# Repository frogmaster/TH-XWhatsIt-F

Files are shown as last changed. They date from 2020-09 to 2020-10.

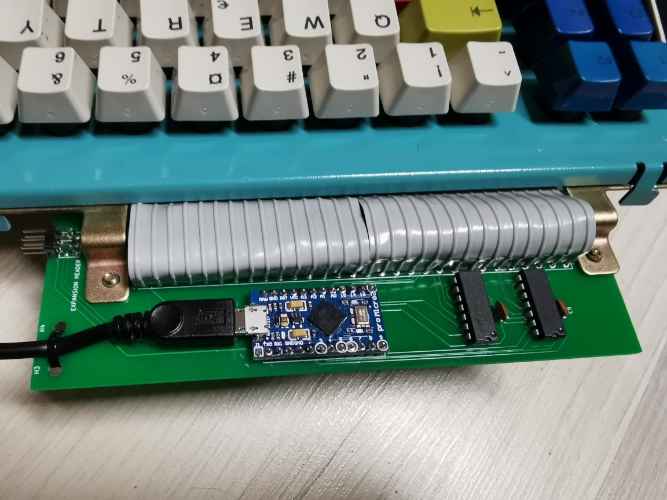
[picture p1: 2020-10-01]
model_f_at_board.jpg

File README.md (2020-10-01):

Derived from:

https://github.com/listofoptions/TH-XWhatsIt

through hole implementation of the capsense controllers by XWhatsIt
(Tom Wong-Cornell). original liscencure holds, as well as CERN OSH
(compatible license).

original implementation of Tom Wong-Cornell's controller documented here

http://downloads.cornall.co/ibm-capsense-usb-web/ibm-capsense-usb.html

component documentation is supplied, working theory of operation is under
the previous link.

Layout changed to accomodate IBM Model F PC/AT keyboard, mainly because i have that one. 
May fit other model F-s with similar setup.

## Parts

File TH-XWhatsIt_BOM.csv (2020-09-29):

Id | Designator | Package | Quantity | Designation | Supplier and ref
1 | U7 | ProMicro | 1 | ProMicro
2 | J2 | PinHeader_1x12_P2.54mm_Vertical | 1 | ROWS
3 | J1 | PinHeader_1x27_P2.54mm_Vertical | 1 | COLUMNS
4 | J8 | PinSocket_1x12_P2.54mm_Vertical | 1 | BEAMSPRING PLUGBOARD ROWS
5 | J11 | PinSocket_1x12_P2.54mm_Vertical | 1 | DISPLAYWRITER PLUGBOARD ROWS
6 | J5 | PinSocket_1x12_P2.54mm_Vertical | 1 | MODEL F PLUGBOARD ROWS
7 | J9 | PinSocket_1x27_P2.54mm_Vertical | 1 | DISPLAYWRITER PLUGBOARD COLUMNS
8 | J3 | PinSocket_1x27_P2.54mm_Vertical | 1 | MODEL F PLUGBOARD COLUMNS
9 | J6 | PinSocket_1x27_P2.54mm_Vertical | 1 | BEAMSPRING PLUGBOARD COLUMNS
10 | J10 | DIP-60_155_ELL | 1 | DISPLAYWRITER PLUGBOARD CONNECTOR
11 | J4 | PinHeader_1x30_P2.54mm_Horizontal | 1 | MODEL F PLUGBOARD CONNECTOR
12 | J7 | 3..6mm_cardedge | 1 | BEAMSPRING PLUGBOARD CONNECTOR
13 | U1,U6 | DIP-14_W7.62mm | 2 | LM339
14 | R6,R5,R1 | R_Axial_DIN0204_L3.6mm_D1.6mm_P1.90mm_Vertical | 3 | 4K7
15 | R2,R7 | R_Axial_DIN0204_L3.6mm_D1.6mm_P1.90mm_Vertical | 2 | 1K
16 | RN3,RN1 | R_Array_SIP5 | 2 | 100K
17 | J12 | PinHeader_2x03_P2.54mm_Vertical | 1 | EXPANSION HEADER
18 | RN2,RN4 | R_Array_SIP5 | 2 | 10K
19 | C3,C4,C5,C7,C8,C9,C10 | C_Disc_D3.0mm_W1.6mm_P2.50mm | 7 | 0U1
20 | R3,R4 | R_Axial_DIN0204_L3.6mm_D1.6mm_P1.90mm_Vertical | 2 | 20K
21 | U2 | DIP-8_W7.62mm | 1 | MCP4921-EP
22 | U8,U5,U3 | DIP-16_W7.62mm | 3 | 74HCT595
23 | C2 | C_Disc_D3.0mm_W1.6mm_P2.50mm | 1 | 10U
24 | H1,H2,H3,H4 | MountingHole_2.2mm_M2_Pad_Via | 4 | GROUND STRAP

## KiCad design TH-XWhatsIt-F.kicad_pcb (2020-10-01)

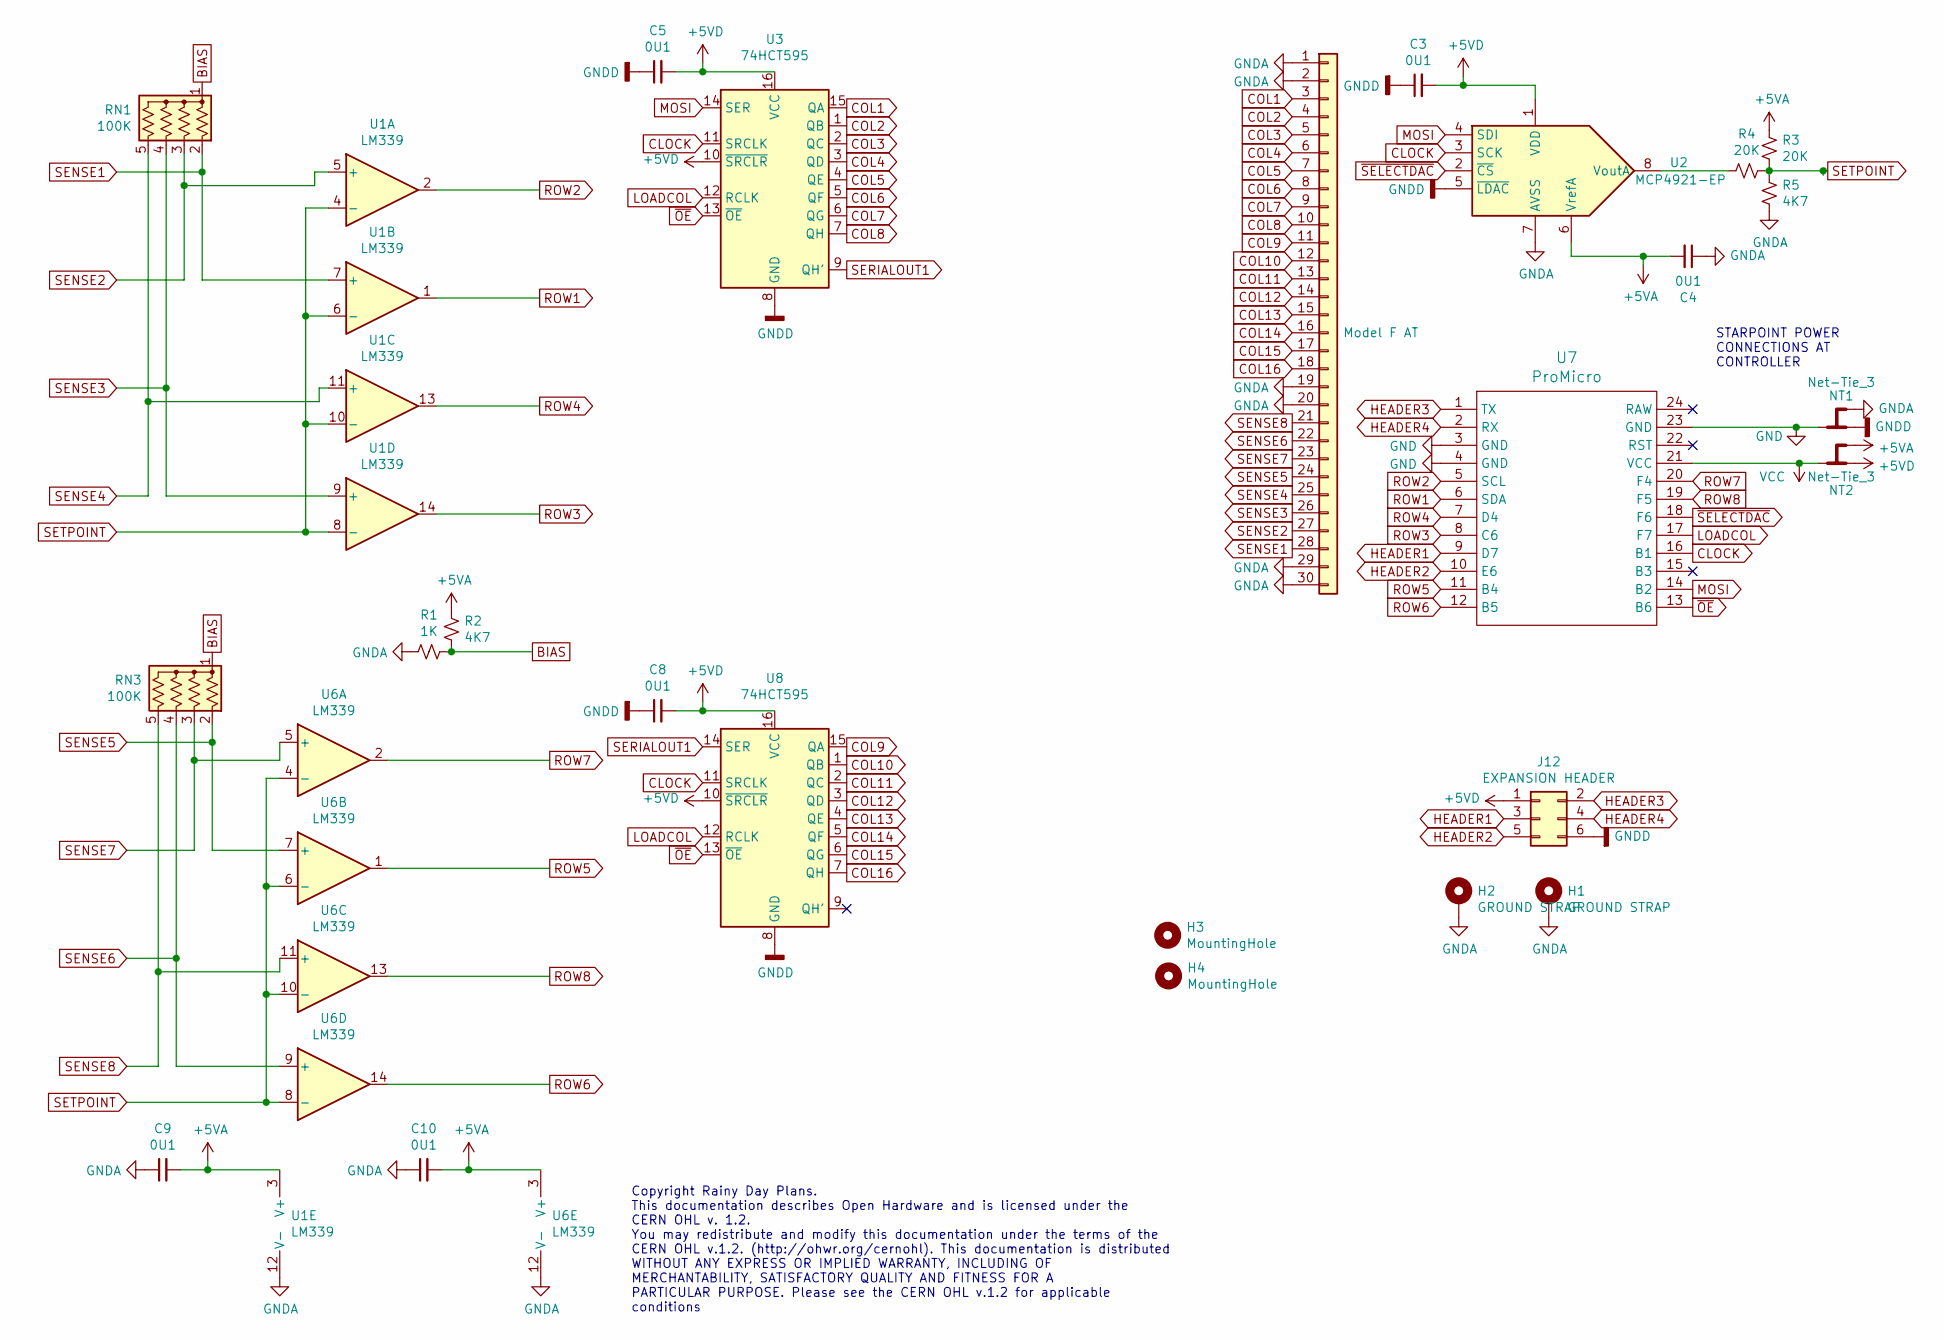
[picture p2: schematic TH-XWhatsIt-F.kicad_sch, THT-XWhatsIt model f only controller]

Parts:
C3, C4, C5, C8, C9, C10: 0U1; C_Disc_D3.0mm_W1.6mm_P2.50mm
H1, H2: GROUND STRAP; MountingHole_4.5mm_Pad
H3, H4: MountingHole; MountingHole_3.2mm_M3
J12: EXPANSION HEADER; PinHeader_2x03_P2.54mm_Vertical
J13: Model F AT; SIP-30-P3.96
NT1, NT2: Net-Tie_3; NetTie-3_THT_Pad1.0mm_mod_thicker
R1: 1K; R_Axial_DIN0204_L3.6mm_D1.6mm_P7.62mm_Horizontal
R2, R5: 4K7; R_Axial_DIN0204_L3.6mm_D1.6mm_P7.62mm_Horizontal
R3, R4: 20K; R_Axial_DIN0204_L3.6mm_D1.6mm_P7.62mm_Horizontal
RN1, RN3: 100K; R_Array_SIP5
U1, U6: LM339; DIP-14_W7.62mm
U2: MCP4921-EP; DIP-8_W7.62mm
U3, U8: 74HCT595; DIP-16_W7.62mm
U7: ProMicro

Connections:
+5VA: C4.2, C9.2, C10.2, NT2.3, R2.1, R3.2, U1.3 (V+), U2.6 (VrefA), U6.3 (V+)
+5VD: C3.2, C5.2, C8.2, J12.1, NT2.1, U2.1 (VDD), U3.10 (~SRCLR), U3.16 (VCC), U8.10 (~SRCLR), U8.16 (VCC)
BIAS: R1.1, R2.2, RN1.1 (common), RN3.1 (common)
CLOCK: U2.3 (SCK), U3.11 (SRCLK), U7.16 (B1), U8.11 (SRCLK)
COL1: J13.3, U3.15 (QA)
COL2: J13.4, U3.1 (QB)
COL3: J13.5, U3.2 (QC)
COL4: J13.6, U3.3 (QD)
COL5: J13.7, U3.4 (QE)
COL6: J13.8, U3.5 (QF)
COL7: J13.9, U3.6 (QG)
COL8: J13.10, U3.7 (QH)
COL9: J13.11, U8.15 (QA)
COL10: J13.12, U8.1 (QB)
COL11: J13.13, U8.2 (QC)
COL12: J13.14, U8.3 (QD)
COL13: J13.15, U8.4 (QE)
COL14: J13.16, U8.5 (QF)
COL15: J13.17, U8.6 (QG)
COL16: J13.18, U8.7 (QH)
GND: NT1.2, U7.3 (GND), U7.4 (GND), U7.23 (GND)
GNDA: C4.1, C9.1, C10.1, H1.1, H2.1, J13.1, J13.2, J13.19, J13.20, J13.29, J13.30, NT1.3, R1.2, R5.1, U1.12 (V-), U2.7 (AVSS), U6.12 (V-)
GNDD: C3.1, C5.1, C8.1, J12.6, NT1.1, U2.5 (~LDAC~), U3.8 (GND), U8.8 (GND)
HEADER1: J12.3, U7.9 (D7)
HEADER2: J12.5, U7.10 (E6)
HEADER3: J12.2, U7.1 (TX)
HEADER4: J12.4, U7.2 (RX)
LOADCOL: U3.12 (RCLK), U7.17 (F7), U8.12 (RCLK)
MOSI: U2.4 (SDI), U3.14 (SER), U7.14 (B2)
unnamed: R4.2, U2.8 (VoutA)
ROW1: U1.1, U7.6 (SDA)
ROW2: U1.2, U7.5 (SCL)
ROW3: U1.14, U7.8 (C6)
ROW4: U1.13, U7.7 (D4)
ROW5: U6.1, U7.11 (B4)
ROW6: U6.14, U7.12 (B5)
ROW7: U6.2, U7.20 (F4)
ROW8: U6.13, U7.19 (F5)
SENSE1: J13.28, RN1.2 (R1), U1.7 (+)
SENSE2: J13.27, RN1.3 (R2), U1.5 (+)
SENSE3: J13.26, RN1.4 (R3), U1.9 (+)
SENSE4: J13.25, RN1.5 (R4), U1.11 (+)
SENSE5: J13.24, RN3.2 (R1), U6.7 (+)
SENSE6: J13.22, RN3.4 (R3), U6.9 (+)
SENSE7: J13.23, RN3.3 (R2), U6.5 (+)
SENSE8: J13.21, RN3.5 (R4), U6.11 (+)
SERIALOUT1: U3.9 (QH'), U8.14 (SER)
SETPOINT: R3.1, R4.1, R5.2, U1.4 (-), U1.6 (-), U1.8 (-), U1.10 (-), U6.4 (-), U6.6 (-), U6.8 (-), U6.10 (-)
VCC: NT2.2, U7.21 (VCC)
~OE: U3.13 (~OE), U7.13 (B6), U8.13 (~OE)
~SELECTDAC: U2.2 (~CS~), U7.18 (F6)

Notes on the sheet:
Copyright Rainy Day Plans. This documentation describes Open Hardware and is licensed under the CERN OHL v. 1.2. You may redistribute and modify this documentation under the terms of the CERN OHL v.1.2. (http://ohwr.org/cernohl). This documentation is distributed WITHOUT ANY EXPRESS OR IMPLIED WARR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
STARPOINT POWER CONNECTIONS AT CONTROLLER

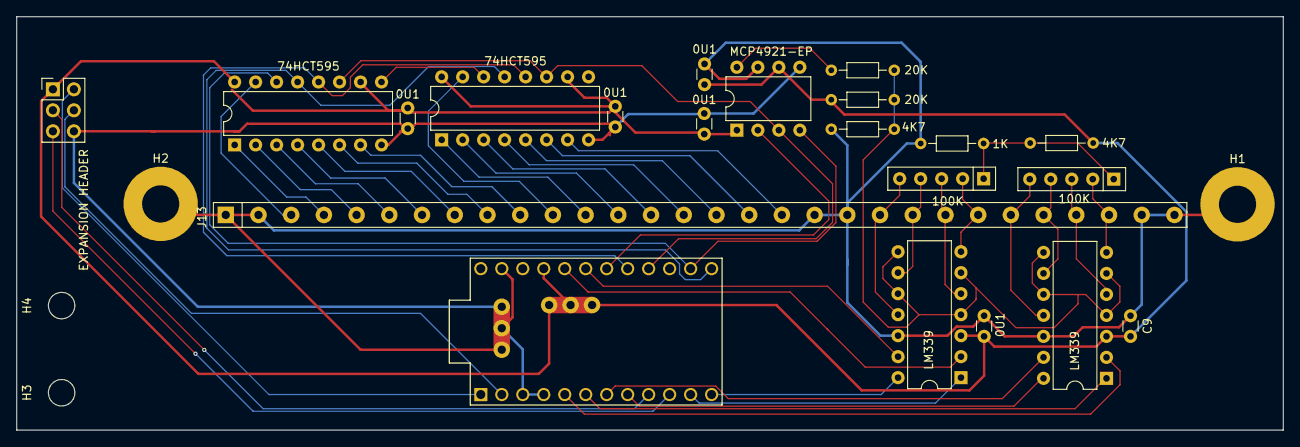
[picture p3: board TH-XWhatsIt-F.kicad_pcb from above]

Board: 2 copper layers, 153.3 x 50.0 mm, 27 parts (0 on the bottom side), 51 nets.

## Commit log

2020-09-29 Copied and modified from TH-XWhatsIt
    [Gerber_BoardOutline.GKO, Gerber_BottomLayer.GBL, Gerber_BottomSilkLayer.GBO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]
2020-10-01 remove old kicad files
    [TH-XWhatsIt-F.sch]
2020-10-01 add new gerbers
    [Gerber_BoardOutline.GKO, Gerber_BottomLayer.GBL, Gerber_BottomSilkLayer.GBO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]
2020-10-01 change gerber output dir
    [TH-XWhatsIt-F.kicad_pcb]

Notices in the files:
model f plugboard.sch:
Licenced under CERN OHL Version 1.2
